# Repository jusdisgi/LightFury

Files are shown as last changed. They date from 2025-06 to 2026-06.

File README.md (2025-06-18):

# Light Fury

This is a 54-key, ergonomic split keyboard with a few tricks. Some of the features include:
- 1.69in color [LCD screen](https://www.waveshare.com/product/displays/lcd-oled/lcd-oled-3/1.69inch-lcd-module.htm)
- Per-key LEDs, using [WS2812B-2020](https://www.adafruit.com/product/4684)
- A roller encoder based on [CKW12](https://github.com/kumamuk-git/CKW12/tree/main) by Kumamuk, but integrated into the main PCB
- Kailh [PG1316S](https://holykeebs.com/products/kailh-pg1316s-butterfly-switch-10-pack) ultra-low profile switches
- A totally absurd [battery](https://www.digikey.com/en/products/detail/maker-emporium-ltd/PIS-1131/13283430) to run all of this stuff...5Ahr!!

## Schematics and Ergogen, just like PB and Chocolate!
If that seems absurd to you, you need to read [my new doc](https://github.com/jusdisgi/LightFury/blob/main/Schematics_and_Ergogen.md)

## Work in Progress

I think it might be done? Could it be?
Please take a look and let me know if you see anything wrong!

## Where is everything?
[Left Half PCB](https://github.com/jusdisgi/LightFury/blob/main/lightfury_left.kicad_pcb)
[Right Half PCB](https://github.com/jusdisgi/LightFury/blob/main/lightfury_right.kicad_pcb)

[Left Half Schematic](https://github.com/jusdisgi/LightFury/blob/main/lightfury_left.kicad_sch)
[Right Half Schematic](https://github.com/jusdisgi/LightFury/blob/main/lightfury_right.kicad_sch)

[Ergogen Config](https://github.com/jusdisgi/LightFury/blob/main/config.yaml)

## Some pics of the design



*the name has been chosen by the intended end-user, but will not be applied to the board until it actually exists in the real world.

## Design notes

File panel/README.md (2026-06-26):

# LightFury panelization (KiKit)

Run on **your machine** (KiKit drives KiCad's `pcbnew` — it won't run in the sandbox). The
per-half boards (`lightfury_left/right.kicad_pcb`) are the source of truth; everything below
rebuilds the combined board and panel from them, so re-run it any time a half changes.

**Environment:** use the **KiCad Command Prompt** (so `python` = KiCad's Python with `pcbnew`).
KiKit's `kikit.exe` installs to `...KiCad\9.0\3rdparty\Python311\Scripts`, which isn't on PATH by
default — add it for the session before the `kikit` commands:

```bat
set PATH=%PATH%;C:\Users\hunte\Documents\KiCad\9.0\3rdparty\Python311\Scripts
```

## Full workflow (in order)

```bash
cd LightFury

# 1. Merge the two halves -> lightfury_both.kicad_pcb (right-half refs get a _2 suffix,
#    nets get L_/R_ prefixes so the halves stay electrically distinct). Replaces the old
#    by-hand merge.
python panel/merge_both.py

# 2. Frame it into a panel.
kikit panelize -p panel/lightfury.kikit.json lightfury_both.kicad_pcb panel/lightfury_panel.kicad_pcb

# 3. GERBERS ONLY from the panel: open it in pcbnew and run the **Fabrication Toolkit** plugin
#    (NOT `kikit fab jlcpcb` — needs a schematic the _2 refs can't match). It writes to the
#    transient panel/production/ ; copy the gerber zip up to the canonical order folder:
copy panel\production\lightfury_panel.zip production-panel\

# 4. BOM + CPL straight from the panel (origin datum, integer rotations, RESW1 injected,
#    per-part offsets) -> the canonical production-panel/ . Then render to verify locally.
python panel/gen_cpl.py panel/lightfury_panel.kicad_pcb production-panel
python panel/render_cpl.py panel/lightfury_panel.kicad_pcb production-panel/positions.csv panel/verify
```

The three files you upload to JLC live in **production-panel/**. Full detail + the one-time JLC
rotation-confirmation step: **CPL_WORKFLOW.md**.

## Notes / gotchas

- **`post.millradius` eats the RE1 foot cutouts.** The CKW12 encoder has two ~2 mm diamond
  (45°-square) Edge.Cuts cutouts per half for RE1's feet. `millradius` simulates a 1 mm-radius
  (2 mm Ø) router bit across the *whole* substrate — including internal holes — so a sub-bit-size
  cutout gets erased. Result: the diamonds are in `lightfury_both` but vanish from the panel.
  Fix is in the preset: use **`millradiusouter`** (mills only the outer ring, leaves internal
  cutouts intact) instead of `millradius`. If your KiKit predates `millradiusouter`, set
  `millradius` to `0mm` and re-inject the 4 diamonds afterward (translate the both-board loops by
  the panel placement offset — footprint-only, so BOM/CPL are untouched). **Always eyeball the
  encoder cutouts in the panel before ordering.**
- **`merge_both.py`** is the script that replaces your old hand-merge. Right-half refs become
  `*_2` (uniform — simpler than the old mixed RS/RLED/_2 scheme; JLC only cares that refs are
  unique and that BOM ↔ CPL agree, which they will since both come from this pipeline).
  `appendBoard`'s signature is the line most likely to need a tweak for your KiKit version.
- **Prereq:** the per-half schematics need their `LCSC` fields filled and pushed to the PCBs
  (Update PCB from Schematic / F8) *before* step 1, or the BOM comes out without part numbers.
- **`gen_cpl.py`** (pure Python, no pcbnew) builds the BOM + CPL directly from the panel: position
  = footprint origin, per-LCSC `ROT_CORR`/`POS_OVERRIDE` tables, and RESW1 (C262417) injected from
  the encoder's S1/S2 pads. It supersedes the old `inject_resw1.py` (now in `old_cruft/`).
  `render_cpl.py` overlays the result on the real pads for local verification before uploading.
- The preset's 1×1 grid frames the merged pair (two outlines) as one unit, bridging each half
  to the rails with mouse-bite tabs. If KiKit complains about the two outlines, the fallback is
  to move framing into `merge_both.py` (KiKit Python API) — ping me and I'll extend it.

## Preset details (lightfury.kikit.json)

- **Rails** top & bottom, 5 mm, 3 mm gap (`railstb`).
- **Tabs** every 25 mm, 3 mm wide, **mouse-bites** (0.5 mm drills @ 0.8 mm) — better than V-cuts
  for the filleted/curved outlines.
- **Tooling holes** (1.5 mm) and **fiducials** (1 mm copper / 2 mm mask) in the rail corners.
- `JLCJLCJLCJLC` order token in the rail, `millradius 1 mm` for the router.

## Tune after first run

- Tighten `GAP_MM` in `merge_both.py` if the halves sit too far apart (tighter = cheaper panel).
- Check the panel against JLC's rules (min rail width, mouse-bite spacing); bump tab count if any
  edge feels under-supported for the 5 Ah / LCD weight during assembly.
- Verify RESW1 (and any consigned/extended parts) in JLC's BOM/assembly preview before ordering.

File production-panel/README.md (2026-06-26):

# LightFury — JLCPCB order set

**These three files are what you upload to JLCPCB. Nothing else.**

| file | what it is | upload as |
|---|---|---|
| `lightfury_panel.zip` | Gerbers + drill for the full panel (both halves, frame, mouse-bites) | Gerber |
| `bom.csv` | Bill of materials (one line per LCSC part, RESW1 included) | BOM |
| `positions.csv` | Pick-and-place / CPL (origin datum, integer rotations, per-part offsets applied) | CPL |

The gerber is uploaded once at the **start** of the JLC order (before PCBA). The BOM/CPL are
uploaded in the PCBA step and can be re-uploaded freely. **You only need a fresh gerber when the
copper changes** (re-panelize or a half edit) — pure rotation/position tweaks ride on the CPL alone.

## Regenerating these

Full procedure and the hard rules live in [`../panel/CPL_WORKFLOW.md`](../panel/CPL_WORKFLOW.md).
Short version, run from the repo root, all from the **same** panel generation:

```bat
:: gerbers: open panel\lightfury_panel.kicad_pcb in KiCad, run the Fabrication Toolkit,
:: then copy its output zip up here:
copy panel\production\lightfury_panel.zip production-panel\

:: BOM + CPL straight from the same panel file:
python panel\gen_cpl.py panel\lightfury_panel.kicad_pcb production-panel

:: optional local sanity render (writes PNGs to panel\verify\):
python panel\render_cpl.py panel\lightfury_panel.kicad_pcb production-panel\positions.csv panel\verify
```

Gerbers and CPL **must** come from the same panel generation or parts land on stale copper — that
was the multi-hour failure of 18 Jun (a frozen gerber under a changing CPL).

## Part-specific notes baked into `gen_cpl.py`

- Rotations and position offsets for the oddball parts (PWR1, CONN1, RE1, RESW1, the SOT-23s,
  LEDs, diodes, switches) are in the `ROT_CORR` / `POS_OVERRIDE` tables at the top of `gen_cpl.py`.
- **PG1316S** switches are consigned (`C9900170245`); the **nice!nano**, **Waveshare LCD**, JST
  battery connector and M2 mounting holes are hand-assembled — none appear in this BOM/CPL by design.

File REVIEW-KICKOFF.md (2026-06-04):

# LightFury — review & optimize: session kickoff

Goal: review the **already-routed** LightFury board (its README literally asks "let me know if you see
anything wrong"), fix only genuine functional problems, and panel it for JLCPCB. **Preserve the
routing** — regenerate from ergogen only if a real defect forces it (it wipes routing).

## Context
- 54-key ergo split — the "Swiss Army chainsaw" to xiphos's scalpel. Features: 1.69" Waveshare color
  **LCD**, **per-key WS2812B-2020 RGB** (~54/half — heat-sensitive, fine-pitch → this is exactly why
  it must be JLC PCBA, not hot-plate), **CKW12 roller encoder** integrated into the PCB, PG1316S
  switches, an absurd **5Ah battery**, nice!nano.
- Has schematics (`lightfury_left.kicad_sch` / `_right`) built via the `Schematics_and_Ergogen.md`
  workflow (the guide is present in this repo), routed `lightfury_left/right/both.kicad_pcb`, and a
  `Production_JLCPCBA/` folder.
- The workspace `../CLAUDE.md` "Schematics, combined boards & production" section applies.
- **No `CLAUDE.md` yet** — create one (model on `../zmk-config-totem/CLAUDE.md`).

## First steps
1. Read `config.yaml`, the routed PCBs, schematics, and `Production_JLCPCBA/` BOM/CPL. Write
   `LightFury/CLAUDE.md`.
2. **Design review** (what the README invites): verify the **WS2812 data chain** (DIN→DOUT order
   continuous and sane), LED/LCD/encoder power + signal nets, decoupling, and schematic ↔ PCB parity.
   Flag issues — but remember fixes needing a config regen cost the routing.
3. **BOM completeness:** every part needs an LCSC number (LCD module, WS2812B-2020, CKW12 encoder,
   EZmate, power/reset switches, PG1316S consigned `C9900170245`); nano DNP / hand-soldered. Sort out
   what's JLC-stockable vs consigned vs hand-placed.
4. **Panelize with KiKit** (multiboard — this board is large, so nesting matters more for cost): rails,
   mouse-bites, fiducials, tooling. Claude writes the config; Hunter runs it.

git: hands-off — write the commands, don't run them.

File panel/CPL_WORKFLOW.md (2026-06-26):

# LightFury CPL / BOM workflow

How to produce a **correct** JLCPCB pick-and-place (CPL) + BOM for the panel — and why the
old way kept failing. Read this before touching the production files.

## What went wrong last time (so we never repeat it)

The boards, schematics, and gerbers were always fine. Every failure was in the CPL, and the
causes were:

1. **Debugging by eyeballing JLC's web preview.** You can't read an offset vector off a rotated
   2 mm part in a browser, so every "fix" was a guess tested through a slow round-trip.
2. **Four bugs tangled together:** the fractional `TILT=10.9` (→ every part on a `.9°` angle that
   JLC rounds, read as "1° off"); per-part pin-1 rotation corrections; an *origin-vs-centroid*
   position question; and **stale-generation drift** — the CPL being regenerated against a
   different panel than the gerbers that got uploaded.
3. **The pad-centroid "correction" was itself the position bug.** Verified against the board's
   F.Fab body outlines: the footprint **origin already sits at each part's body center**, which is
   exactly JLC's placement datum. The pad centroid is *skewed* on any asymmetric part
   (Molex −1.8 mm, encoder +2.4 mm, all 54 PG1316S +0.9 mm, BAV70 +0.4 mm). The old inject
   script shifted everything to the centroid and dragged good parts off their pads.
4. **Post-hoc deltas on a moving baseline.** Corrections were layered on top of toolkit output
   that itself changed between runs (auto-translate on/off, re-export), and weren't idempotent.

## The rule set we proved correct

- **Position = footprint origin**, nothing else. (Origin = body center = JLC datum for every part
  on this board. Confirmed against F.Fab outlines + the gerber Edge.Cuts bbox.)
- **CPL origin = panel Edge.Cuts top-left**, Y flipped. This is *exactly* the origin KiCad/the
  Fabrication Toolkit uses when it plots the gerbers (gerber bbox `X[0,184.313] Y[-234.012,0]`
  matches the panel bbox `X[56.343,240.657] Y[20,254.012]` — same W/H, tl origin). So CPL and
  gerbers share one frame **by construction** → no global offset.
- **Rotation = footprint orientation + a per-LCSC correction.** Keep `TILT` an **integer** so every
  part lands on a whole degree. Only oriented parts whose pin-1 differs from JLC's library need a
  nonzero correction.
- **Single source of truth.** The CPL is generated directly from `lightfury_panel.kicad_pcb` — the
  same file the gerbers come from. Never hand-patch positions again.

## The tools (pure Python, no pcbnew — run anywhere)

- `kicad_panel.py` — parses the `.kicad_pcb` (footprints, pads, F.Fab outlines, Edge.Cuts bbox).
- `gen_cpl.py` — writes `positions.csv` + `bom.csv` from the panel. Idempotent.
- `render_cpl.py` — draws the placement points over the real copper pads as PNGs for **local**
  verification, so we confirm correctness *before* uploading anything.

## Procedure

Run these on the **same** panel file, in lockstep, every time the board changes:

```bat
cd C:\Users\hunte\Documents\gittyup\LightFury

:: 1. (if layout changed) re-merge + re-panelize so panel matches the halves
python panel\merge_both.py
kikit panelize -p panel\lightfury.kikit.json lightfury_both.kicad_pcb panel\lightfury_panel.kicad_pcb

:: 2. export GERBERS from panel\lightfury_panel.kicad_pcb (Fabrication Toolkit -> panel\production\),
::    then copy the zip up into the canonical order folder:
copy panel\production\lightfury_panel.zip production-panel\

:: 3. generate the CPL + BOM from the SAME panel file, straight into production-panel\
python panel\gen_cpl.py panel\lightfury_panel.kicad_pcb production-panel

:: 4. LOCAL verification — render onto the real pads and eyeball before uploading
python panel\render_cpl.py panel\lightfury_panel.kicad_pcb production-panel\positions.csv panel\verify
start panel\verify\verify_overview.png
start panel\verify\verify_parts.png
```

Upload to JLC: the three files in **`production-panel\`** — `lightfury_panel.zip` + `positions.csv` + `bom.csv`.

## The one remaining manual step: confirm rotations (do this ONCE)

Positions are now exact. The only thing the board geometry can't tell us is how JLC's library part
is oriented on its reel vs our footprint. Resolve it in a **single clean pass** — don't nudge
iteratively:

1. Upload and open JLC's assembly preview.
2. For each **oriented** part type (LED, BAV70 diode, the two SOT-23 ICs, power/reset switches,
   Molex connector, encoder, RESW), read whether it needs 0/90/180/270°. JLC's editor gives exact
   values — read, don't guess.
3. Put each into `ROT_CORR` in `gen_cpl.py`, keyed by LCSC. `C965555` (LED) = 180 is already
   confirmed. Re-run step 3 above (positions are unaffected) and re-upload.

If a part's *body* ever looks off its pads in JLC (not just rotated), that's a datum exception —
add a `POS_OVERRIDE[lcsc] = (dx, dy)` in part-local mm. None are expected on this board.

## Hard rules

- `TILT` in `merge_both.py` stays an **integer**.
- Gerbers and CPL always come from the **same** `lightfury_panel.kicad_pcb` generation. If you
  re-panelize, you re-export both. No mixing generations.
- `inject_resw1.py` is **superseded** by `gen_cpl.py` and kept only for reference. Don't run it.

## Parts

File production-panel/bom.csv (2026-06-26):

Designator | Footprint | Quantity | Value | LCSC Part #
D1, D10, D10_2, D11, D11_2, D12, D12_2, D13, D13_2, D14, D14_2, D1_2, D2, D2_2, D3, D3_2, D4, D4_2, D5, D5_2, D6, D6_2, D7, D7_2, D8, D8_2, D9, D9_2 | BAV70 SOT23 | 28 | BAV70 | C68978
S1, S10, S10_2, S11, S11_2, S12, S12_2, S13, S13_2, S14, S14_2, S15, S15_2, S16, S16_2, S17, S17_2, S18, S18_2, S19, S19_2, S1_2, S2, S20, S20_2, S21, S21_2, S22, S22_2, S23, S23_2, S24, S24_2, S25, S25_2, S26, S26_2, S27, S27_2, S2_2, S3, S3_2, S4, S4_2, S5, S5_2, S6, S6_2, S7, S7_2, S8, S8_2, S9, S9_2 | PG1316S | 54 | PG1316S | C9900170245
R2, R2_2 | Resistor_SMD:R_0603_1608Metric | 2 | 51kΩ | C23196
RE1, RE1_2 | CKW12 | 2 | CKW12 | C202421
LED1, LED10, LED10_2, LED11, LED11_2, LED12, LED12_2, LED13, LED13_2, LED14, LED14_2, LED15, LED15_2, LED16, LED16_2, LED17, LED17_2, LED18, LED18_2, LED19, LED19_2, LED1_2, LED2, LED20, LED20_2, LED21, LED21_2, LED22, LED22_2, LED23, LED23_2, LED24, LED24_2, LED25, LED25_2, LED26, LED26_2, LED27, LED27_2, LED2_2, LED3, LED3_2, LED4, LED4_2, LED5, LED5_2, LED6, LED6_2, LED7, LED7_2, LED8, LED8_2, LED9, LED9_2 | LED_WS2812B-2020_PLCC4_2.0x2.0mm | 54 | WS2812B-2020 | C965555
R1, R1_2 | Resistor_SMD:R_0603_1608Metric | 2 | 470kΩ | C23178
RST1, RST1_2 | ceoloide:reset_switch_smd_side | 2 | Reset SW | C79174
CONN1, CONN1_2 | Molex_PicoBlade_53261-0871_1x08-1MP_P1.25mm_Horizontal | 2 | LCD HEADER | C293349
C2, C2_2, C4, C4_2, C5, C5_2 | Capacitor_SMD:C_0603_1608Metric | 6 | 10μF 25V | C91606
C3, C3_2 | Capacitor_SMD:C_0603_1608Metric | 2 | 100nF | C14663
U2, U2_2 | Package_TO_SOT_SMD:SOT-23-5 | 2 | SN74LV1T126DBVR | C2440228
PWR1, PWR1_2 | ceoloide:power_switch_smd_side | 2 | Power SW | C2911519
L1, L1_2 | huntercook:L_CJIANG_FTC404030S_4.1x4.1x3.0_SMD | 2 | 2.2μH | C39676081
U1, U1_2 | Package_TO_SOT_SMD:SOT-23-6 | 2 | TLV61070ADBV | C6881375
C1, C1_2 | Capacitor_SMD:C_0603_1608Metric | 2 | 10μF | C1691
RESW1, RESW1_2 | CKW12 | 2 | CKW12 Switch | C262417

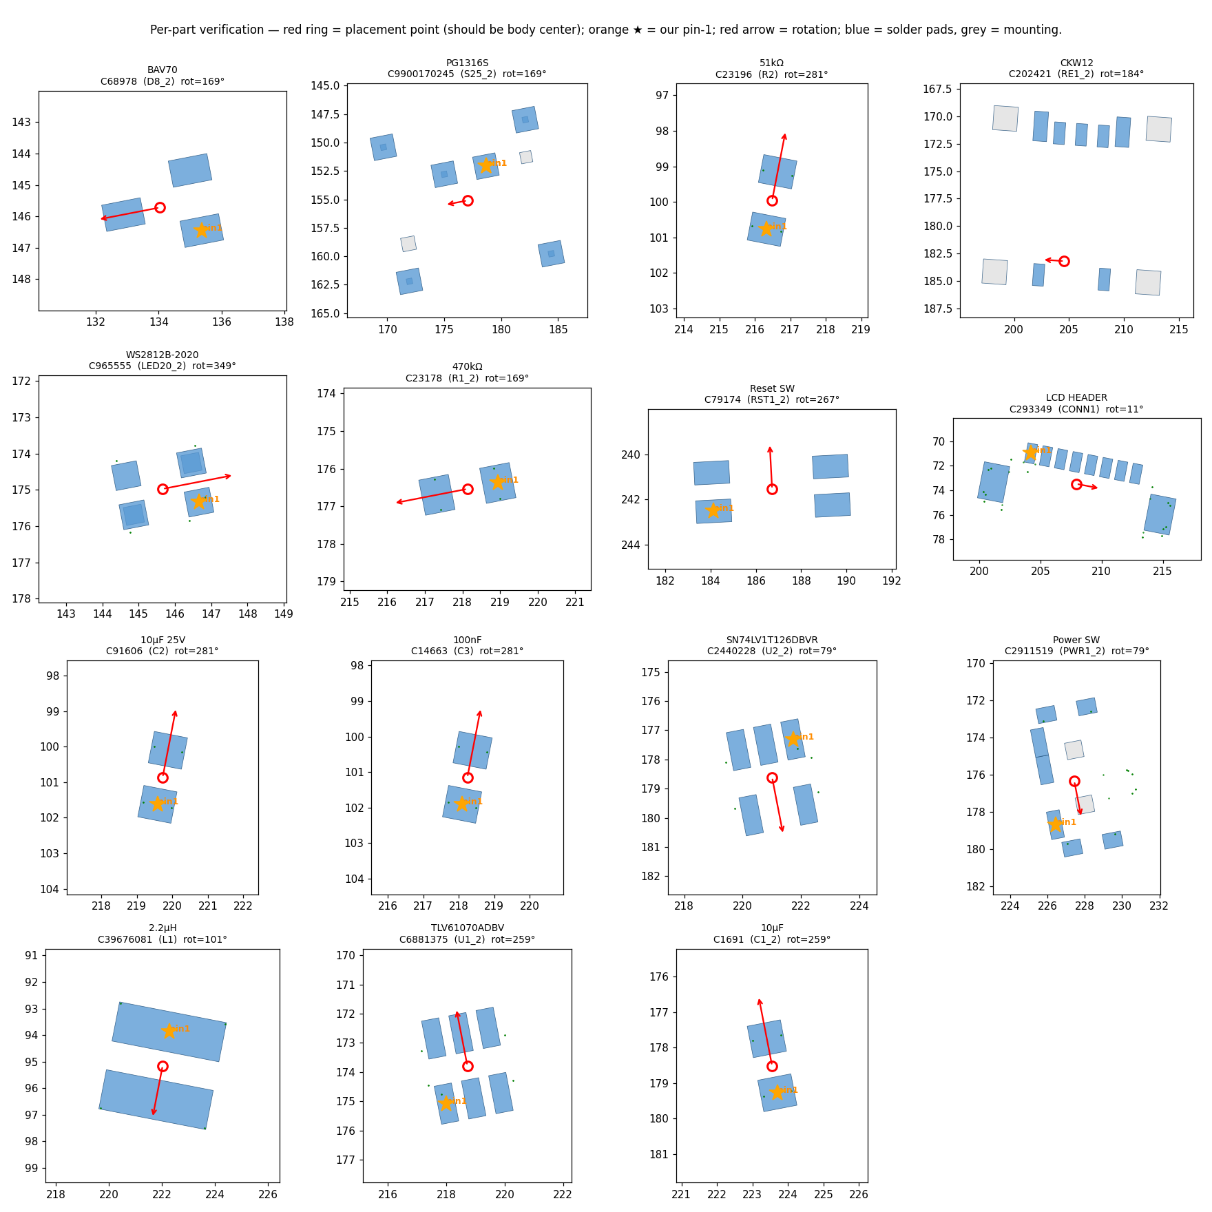
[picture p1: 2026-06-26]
panel/verify/verify_parts.png

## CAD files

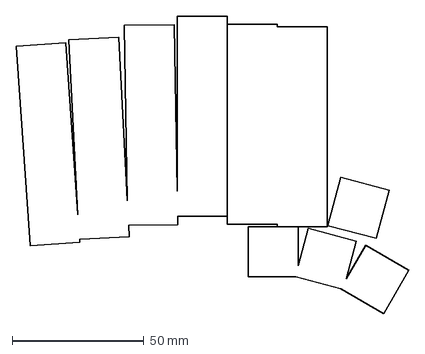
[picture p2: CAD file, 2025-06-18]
output/outlines/case_keycuts_left.dxf
149.3 x 113.1 mm

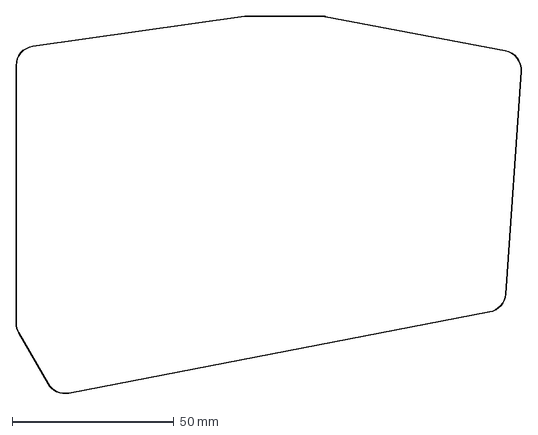
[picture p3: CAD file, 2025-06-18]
output/outlines/board_right.dxf
156.2 x 116.9 mm

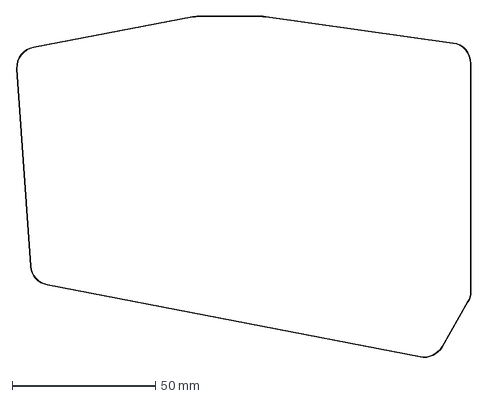
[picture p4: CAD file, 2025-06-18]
output/outlines/case_outer_wall_left.dxf
158.7 x 119.4 mm

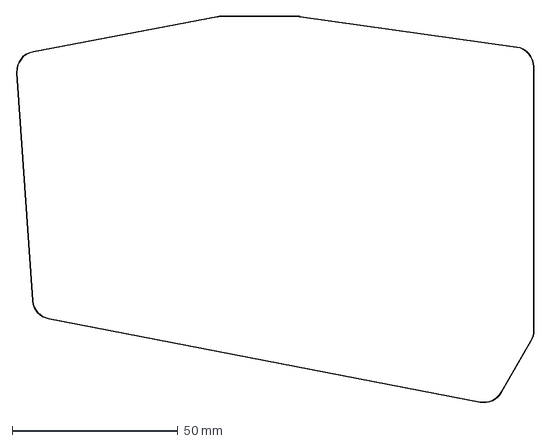
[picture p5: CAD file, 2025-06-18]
output/outlines/board_left.dxf
156.2 x 116.9 mm

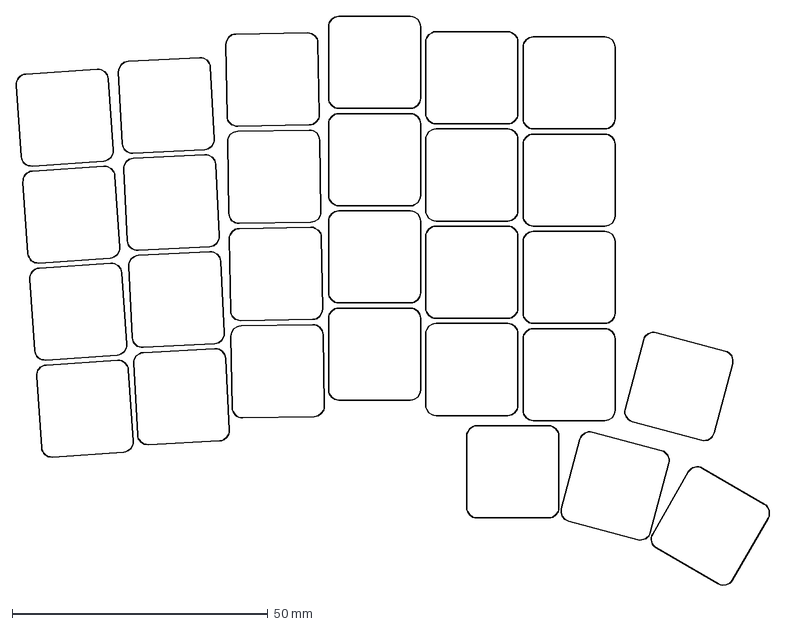
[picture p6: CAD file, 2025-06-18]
output/outlines/keycap_outlines_left.dxf
147.5 x 111.4 mm

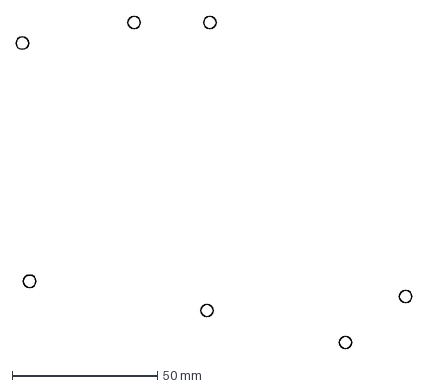
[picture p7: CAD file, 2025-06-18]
output/outlines/spacers_left.dxf
136.0 x 114.3 mm

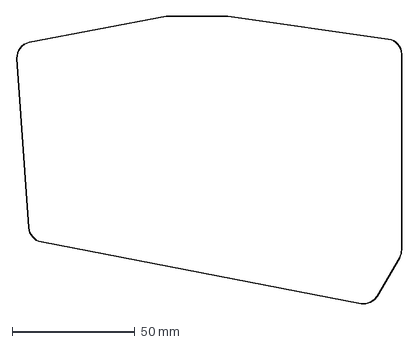
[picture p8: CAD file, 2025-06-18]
output/outlines/case_inner_wall_left.dxf
156.6 x 117.3 mm

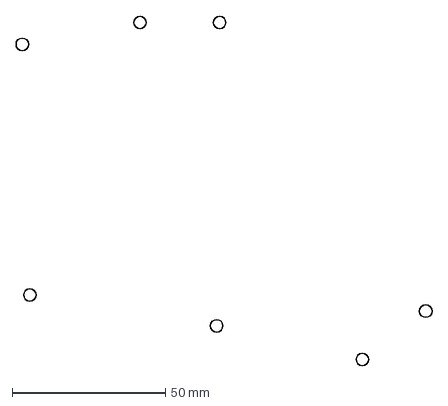
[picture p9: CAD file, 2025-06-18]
output/outlines/screw_heads_left.dxf
135.8 x 114.1 mm

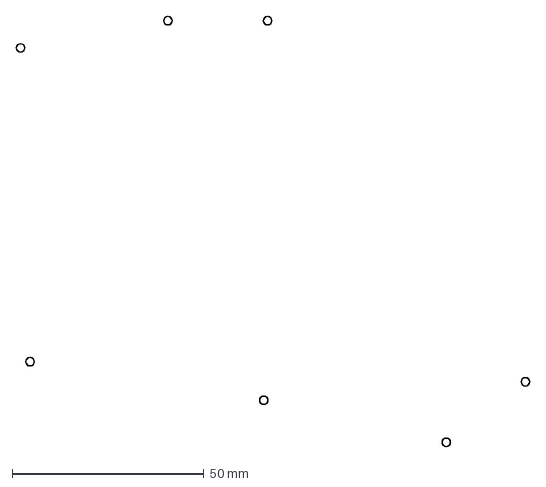
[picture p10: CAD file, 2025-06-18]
output/outlines/screws_left.dxf
133.9 x 112.2 mm

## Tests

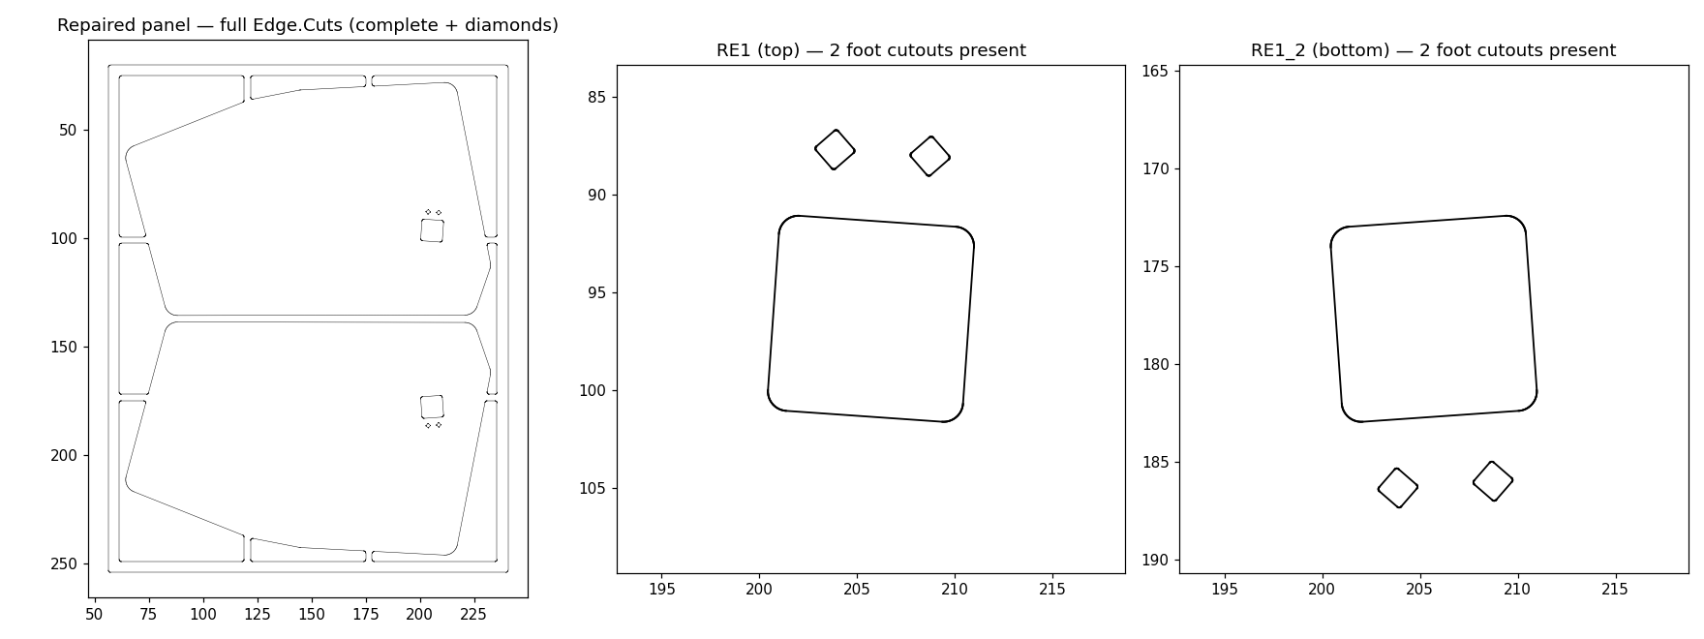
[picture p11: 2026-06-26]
panel/verify/panel_edgecuts_verify.png

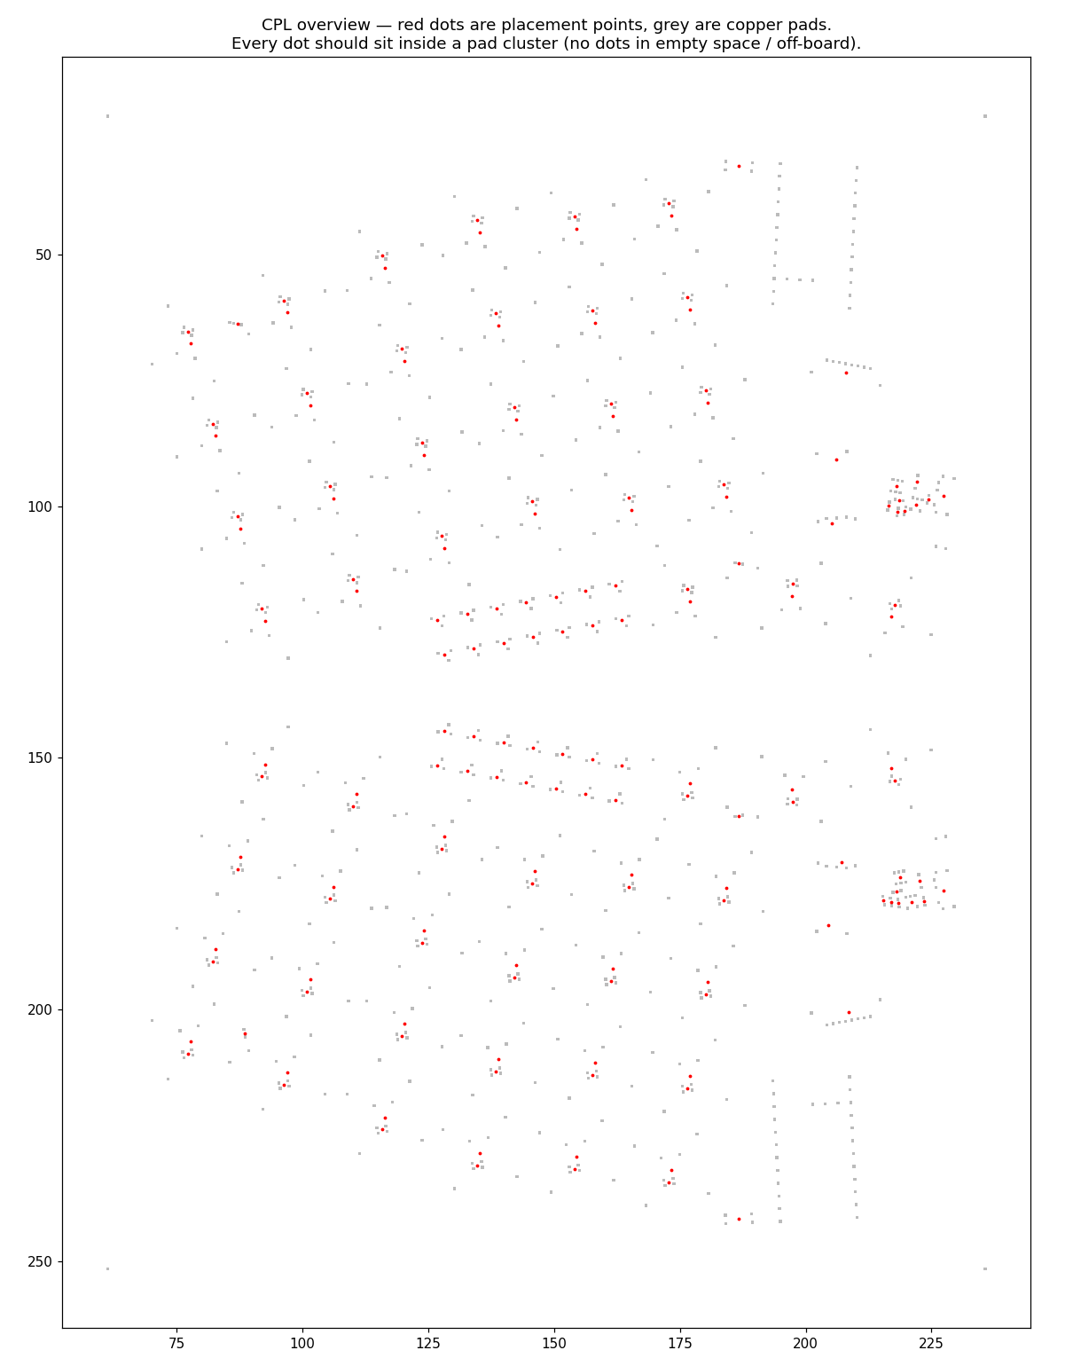
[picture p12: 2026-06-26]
panel/verify/verify_overview.png

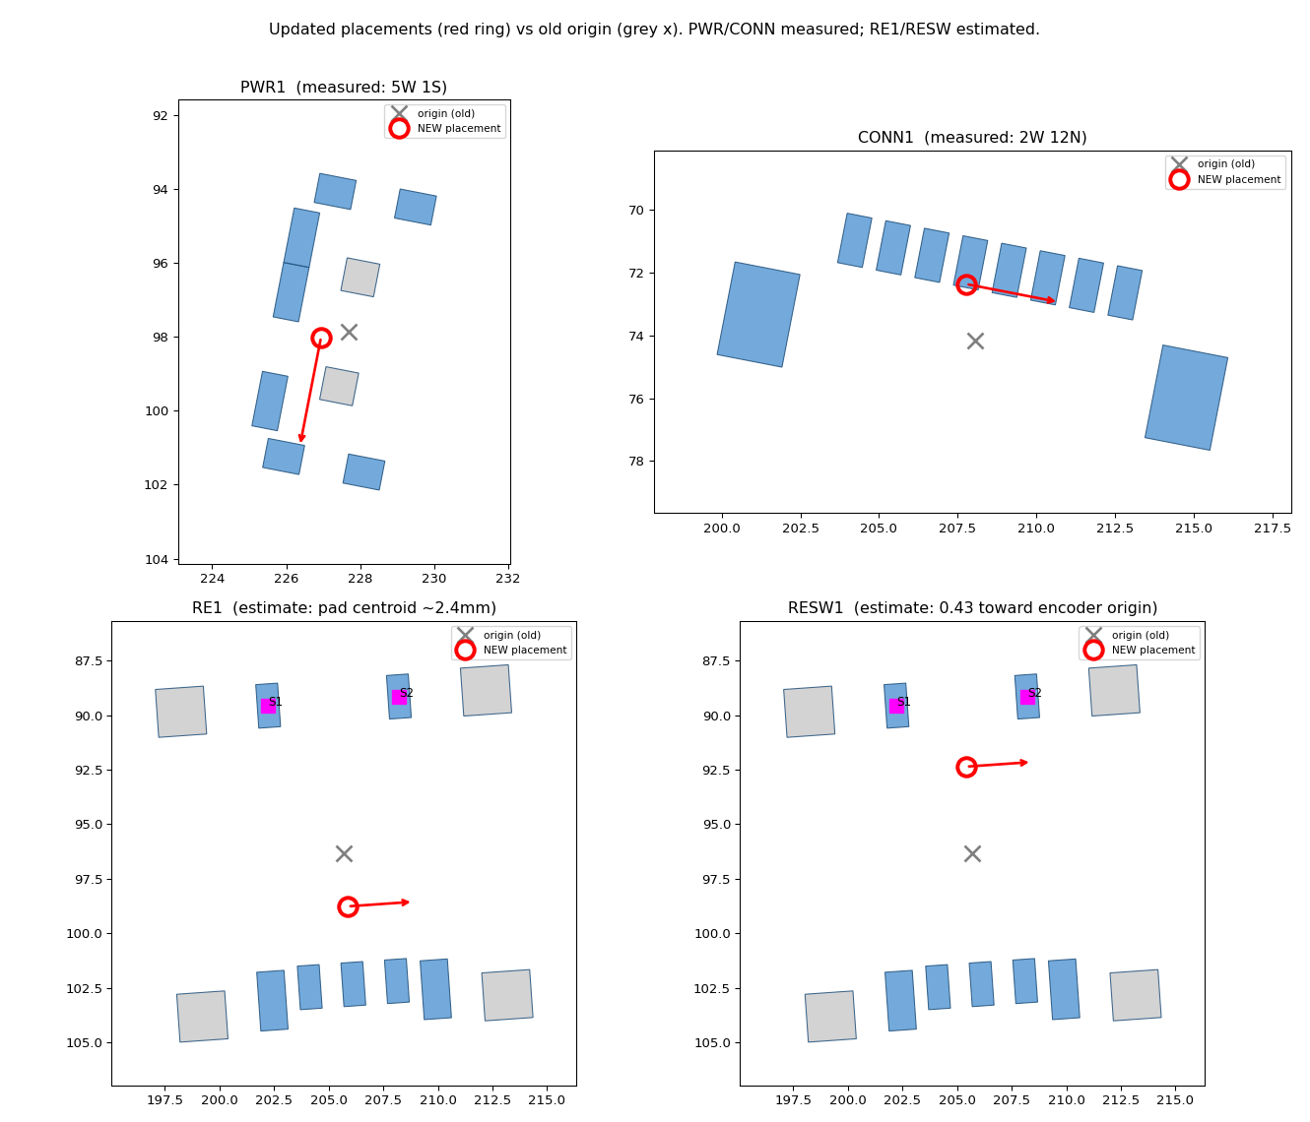
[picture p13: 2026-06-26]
panel/verify/verify_fixed4.png

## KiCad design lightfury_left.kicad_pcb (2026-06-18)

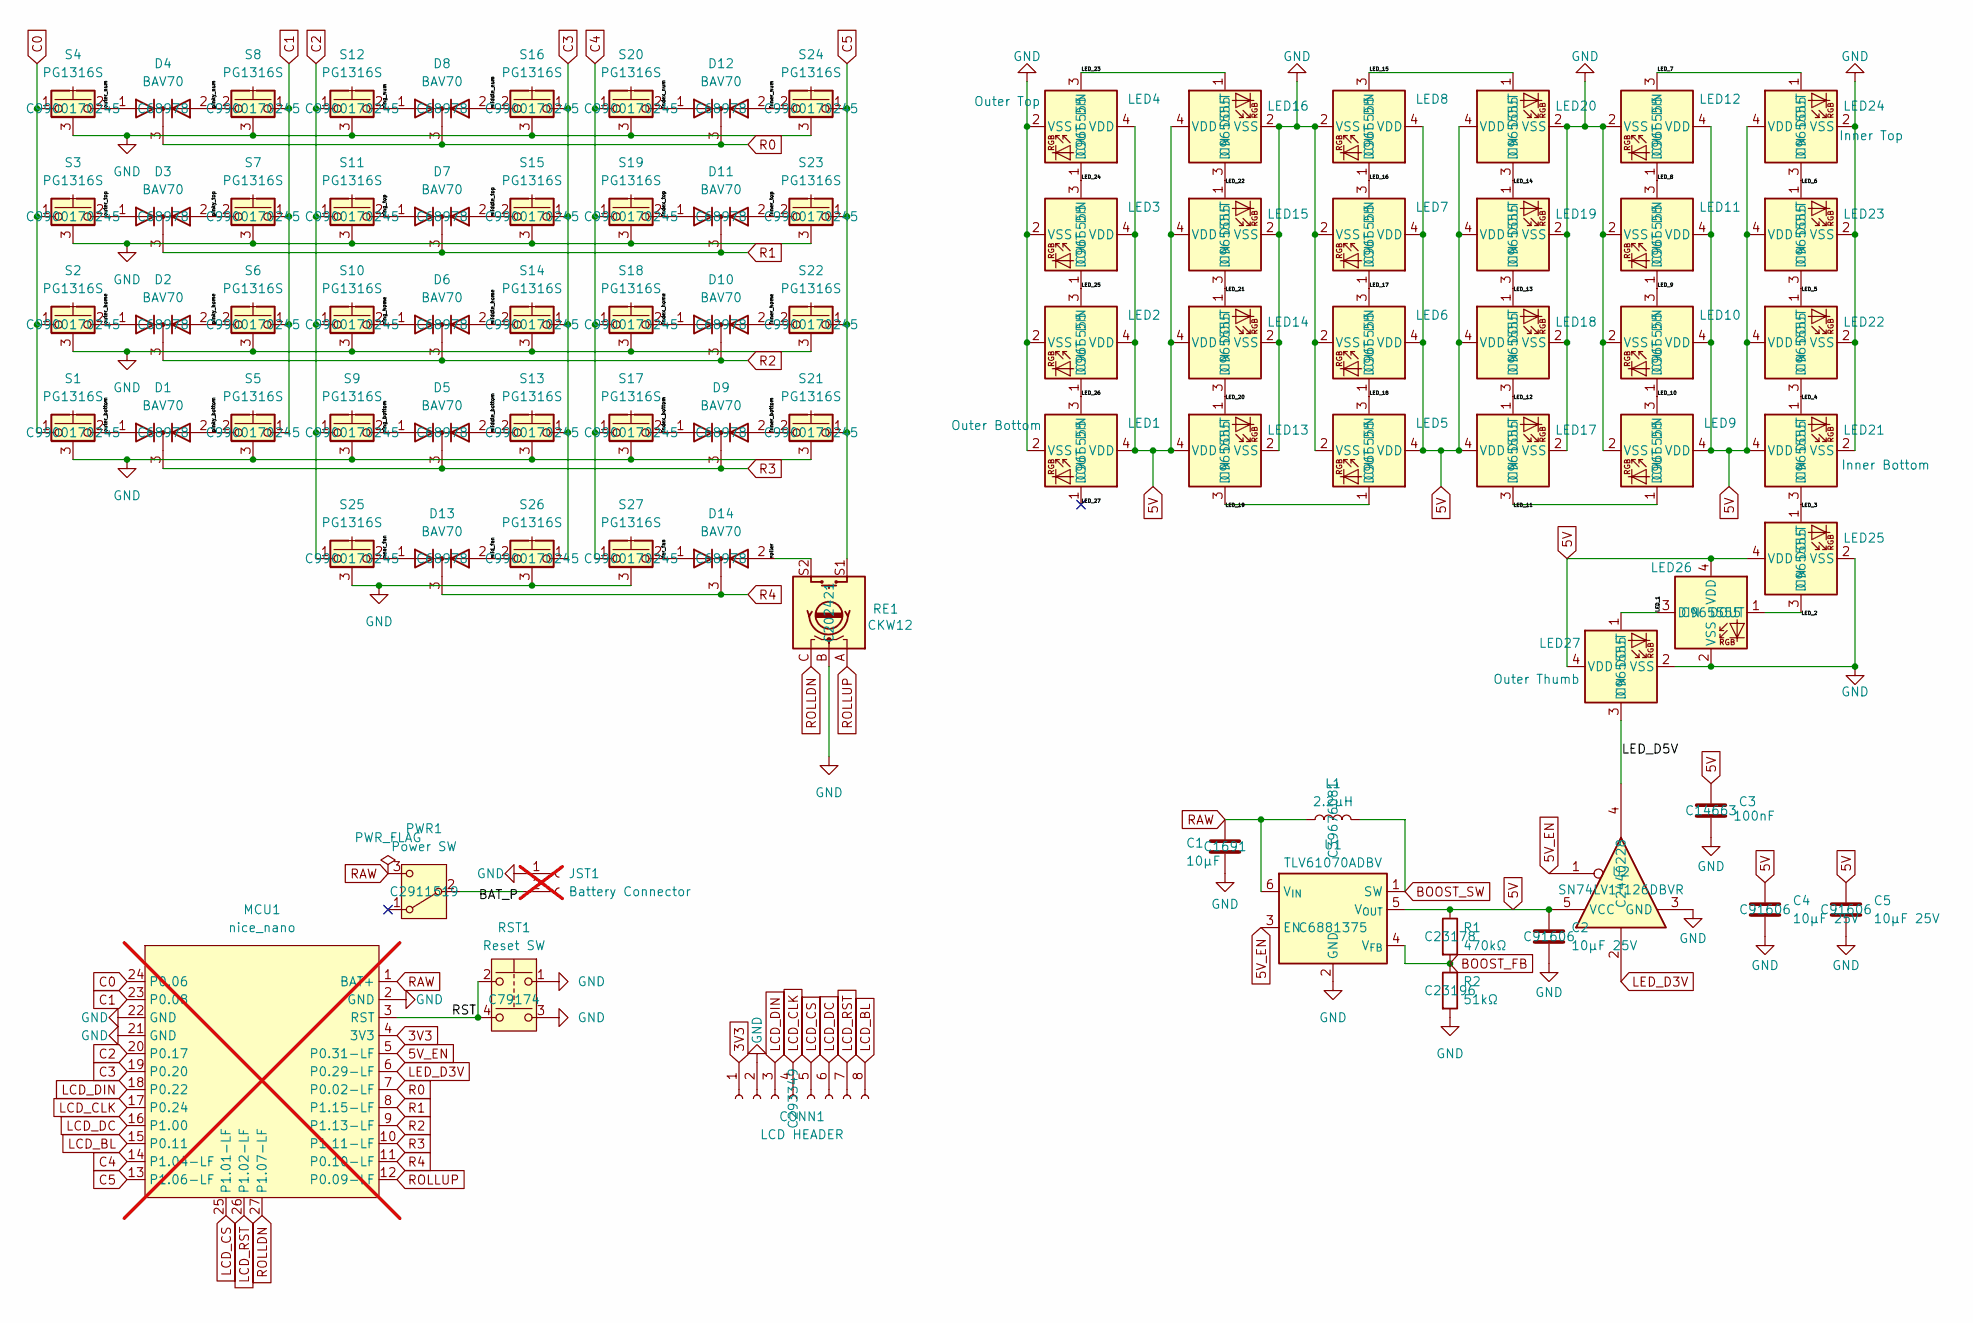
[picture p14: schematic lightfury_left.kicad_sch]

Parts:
C1: 10μF; C_0603_1608Metric; LCSC C1691
C2: 10μF 25V; C_0603_1608Metric; LCSC C91606
C3: 100nF; C_0603_1608Metric; LCSC C14663
C4, C5: 10µF 25V; C_0603_1608Metric; LCSC C91606
CONN1: LCD HEADER; Molex_PicoBlade_53261-0871_1x08-1MP_P1.25mm_Horizontal; LCSC C293349
D1, D2, D3, D4, D5, D6, D7, D8, D9, D10, D11, D12, D13, D14: BAV70; BAV70 SOT23; LCSC C68978
JST1: Battery Connector; battery_connector_jst_ph_2; not fitted
L1: 2.2μH; L_CJIANG_FTC404030S_4.1x4.1x3.0_SMD; LCSC C39676081
LED1: Outer Bottom; LED_WS2812B-2020_PLCC4_2.0x2.0mm; LCSC C965555
LED2, LED3, LED5, LED6, LED7, LED8, LED9, LED10, LED11, LED12, LED13, LED14, LED15, LED16, LED17, LED18, LED19, LED20, LED22, LED23, LED25, LED26: WS2812B-2020; LED_WS2812B-2020_PLCC4_2.0x2.0mm; LCSC C965555
LED4: Outer Top; LED_WS2812B-2020_PLCC4_2.0x2.0mm; LCSC C965555
LED21: Inner Bottom; LED_WS2812B-2020_PLCC4_2.0x2.0mm; LCSC C965555
LED24: Inner Top; LED_WS2812B-2020_PLCC4_2.0x2.0mm; LCSC C965555
LED27: Outer Thumb; LED_WS2812B-2020_PLCC4_2.0x2.0mm; LCSC C965555
MCU1: nice_nano; mcu_nice_nano; not fitted
PWR1: Power SW; power_switch_smd_side; LCSC C2911519
R1: 470kΩ; R_0603_1608Metric; LCSC C23178
R2: 51kΩ; R_0603_1608Metric; LCSC C23196
RE1: CKW12; LCSC C202421
RST1: Reset SW; reset_switch_smd_side; LCSC C79174
S1, S2, S3, S4, S5, S6, S7, S8, S9, S10, S11, S12, S13, S14, S15, S16, S17, S18, S19, S20, S21, S22, S23, S24, S25, S26, S27: PG1316S; LCSC C9900170245
U1: TLV61070ADBV; SOT-23-6; LCSC C6881375
U2: SN74LV1T126DBVR; SOT-23-5; LCSC C2440228

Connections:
3V3: CONN1.1, MCU1.4 (3V3)
5V: C2.1, C3.1, C4.1, C5.1, LED1.4 (VDD), LED2.4 (VDD), LED3.4 (VDD), LED4.4 (VDD), LED5.4 (VDD), LED6.4 (VDD), LED7.4 (VDD), LED8.4 (VDD), LED9.4 (VDD), LED10.4 (VDD), LED11.4 (VDD), LED12.4 (VDD), LED13.4 (VDD), LED14.4 (VDD), LED15.4 (VDD), LED16.4 (VDD), LED17.4 (VDD), LED18.4 (VDD), LED19.4 (VDD), LED20.4 (VDD), LED21.4 (VDD), LED22.4 (VDD), LED23.4 (VDD), LED24.4 (VDD), LED25.4 (VDD), LED26.4 (VDD), LED27.4 (VDD), R1.1, U1.5 (V_{OUT}), U2.5 (VCC)
5V_EN: MCU1.5 (P0.31-LF), U1.3 (EN), U2.1
/BAT_P: JST1.2, PWR1.2 (B)
/LED_1: LED26.3 (DIN), LED27.1 (DOUT)
/LED_2: LED25.3 (DIN), LED26.1 (DOUT)
/LED_3: LED21.3 (DIN), LED25.1 (DOUT)
/LED_4: LED21.1 (DOUT), LED22.3 (DIN)
/LED_5: LED22.1 (DOUT), LED23.3 (DIN)
/LED_6: LED23.1 (DOUT), LED24.3 (DIN)
/LED_7: LED12.3 (DIN), LED24.1 (DOUT)
/LED_8: LED11.3 (DIN), LED12.1 (DOUT)
/LED_9: LED10.3 (DIN), LED11.1 (DOUT)
/LED_10: LED9.3 (DIN), LED10.1 (DOUT)
/LED_11: LED9.1 (DOUT), LED17.3 (DIN)
/LED_12: LED17.1 (DOUT), LED18.3 (DIN)
/LED_13: LED18.1 (DOUT), LED19.3 (DIN)
/LED_14: LED19.1 (DOUT), LED20.3 (DIN)
/LED_15: LED8.3 (DIN), LED20.1 (DOUT)
/LED_16: LED7.3 (DIN), LED8.1 (DOUT)
/LED_17: LED6.3 (DIN), LED7.1 (DOUT)
/LED_18: LED5.3 (DIN), LED6.1 (DOUT)
/LED_19: LED5.1 (DOUT), LED13.3 (DIN)
/LED_20: LED13.1 (DOUT), LED14.3 (DIN)
/LED_21: LED14.1 (DOUT), LED15.3 (DIN)
/LED_22: LED15.1 (DOUT), LED16.3 (DIN)
/LED_23: LED4.3 (DIN), LED16.1 (DOUT)
/LED_24: LED3.3 (DIN), LED4.1 (DOUT)
/LED_25: LED2.3 (DIN), LED3.1 (DOUT)
/LED_26: LED1.3 (DIN), LED2.1 (DOUT)
/LED_27: LED1.1 (DOUT)
/LED_D5V: LED27.3 (DIN), U2.4
/RST: MCU1.3 (RST), RST1.2, RST1.4
/far_fan: D14.1 (A), S27.2
/index_bottom: D9.1 (A), S17.2
/index_home: D10.1 (A), S18.2
/index_num: D12.1 (A), S20.2
/index_top: D11.1 (A), S19.2
/inner_bottom: D9.2 (A), S21.2
/inner_home: D10.2 (A), S22.2
/inner_num: D12.2 (A), S24.2
/inner_top: D11.2 (A), S23.2
/mid_fan: D13.2 (A), S26.2
/middle_bottom: D5.2 (A), S13.2
/middle_home: D6.2 (A), S14.2
/middle_num: D8.2 (A), S16.2
/middle_top: D7.2 (A), S15.2
/near_fan: D13.1 (A), S25.2
/outer_bottom: D1.1 (A), S1.2
/outer_home: D2.1 (A), S2.2
/outer_num: D4.1 (A), S4.2
/outer_top: D3.1 (A), S3.2
/pinky_bottom: D1.2 (A), S5.2
/pinky_home: D2.2 (A), S6.2
/pinky_num: D4.2 (A), S8.2
/pinky_top: D3.2 (A), S7.2
/ring_bottom: D5.1 (A), S9.2
/ring_home: D6.1 (A), S10.2
/ring_num: D8.1 (A), S12.2
/ring_top: D7.1 (A), S11.2
/roller: D14.2 (A), RE1.S2
BOOST_FB: R1.2, R2.1, U1.4 (V_{FB})
BOOST_SW: L1.2, U1.1 (SW)
C0: MCU1.24 (P0.06), S1.1, S2.1, S3.1, S4.1
C1: MCU1.23 (P0.08), S5.1, S6.1, S7.1, S8.1
C2: MCU1.20 (P0.17), S9.1, S10.1, S11.1, S12.1, S25.1
C3: MCU1.19 (P0.20), S13.1, S14.1, S15.1, S16.1, S26.1
C4: MCU1.14 (P1.04-LF), S17.1, S18.1, S19.1, S20.1, S27.1
C5: MCU1.13 (P1.06-LF), RE1.S1, S21.1, S22.1, S23.1, S24.1
GND: C1.2, C2.2, C3.2, C4.2, C5.2, CONN1.2, JST1.1, LED1.2 (VSS), LED2.2 (VSS), LED3.2 (VSS), LED4.2 (VSS), LED5.2 (VSS), LED6.2 (VSS), LED7.2 (VSS), LED8.2 (VSS), LED9.2 (VSS), LED10.2 (VSS), LED11.2 (VSS), LED12.2 (VSS), LED13.2 (VSS), LED14.2 (VSS), LED15.2 (VSS), LED16.2 (VSS), LED17.2 (VSS), LED18.2 (VSS), LED19.2 (VSS), LED20.2 (VSS), LED21.2 (VSS), LED22.2 (VSS), LED23.2 (VSS), LED24.2 (VSS), LED25.2 (VSS), LED26.2 (VSS), LED27.2 (VSS), MCU1.2 (GND), MCU1.21 (GND), MCU1.22 (GND), R2.2, RE1.B, RST1.1, RST1.3, S1.3 (B), S2.3 (B), S3.3 (B), S4.3 (B), S5.3 (B), S6.3 (B), S7.3 (B), S8.3 (B), S9.3 (B), S10.3 (B), S11.3 (B), S12.3 (B), S13.3 (B), S14.3 (B), S15.3 (B), S16.3 (B), S17.3 (B), S18.3 (B), S19.3 (B), S20.3 (B), S21.3 (B), S22.3 (B), S23.3 (B), S24.3 (B), S25.3 (B), S26.3 (B), S27.3 (B), U1.2 (GND), U2.3 (GND)
LCD_BL: CONN1.8, MCU1.15 (P0.11)
LCD_CLK: CONN1.4, MCU1.17 (P0.24)
LCD_CS: CONN1.5, MCU1.25 (P1.01-LF)
LCD_DC: CONN1.6, MCU1.16 (P1.00)
LCD_DIN: CONN1.3, MCU1.18 (P0.22)
LCD_RST: CONN1.7, MCU1.26 (P1.02-LF)
LED_D3V: MCU1.6 (P0.29-LF), U2.2
R0: D4.3 (K), D8.3 (K), D12.3 (K), MCU1.7 (P0.02-LF)
R1: D3.3 (K), D7.3 (K), D11.3 (K), MCU1.8 (P1.15-LF)
R2: D2.3 (K), D6.3 (K), D10.3 (K), MCU1.9 (P1.13-LF)
R3: D1.3 (K), D5.3 (K), D9.3 (K), MCU1.10 (P1.11-LF)
R4: D13.3 (K), D14.3 (K), MCU1.11 (P0.10-LF)
RAW: C1.1, L1.1, MCU1.1 (BAT+), PWR1.3 (C), U1.6 (V_{IN})
ROLLDN: MCU1.27 (P1.07-LF), RE1.C
ROLLUP: MCU1.12 (P0.09-LF), RE1.A

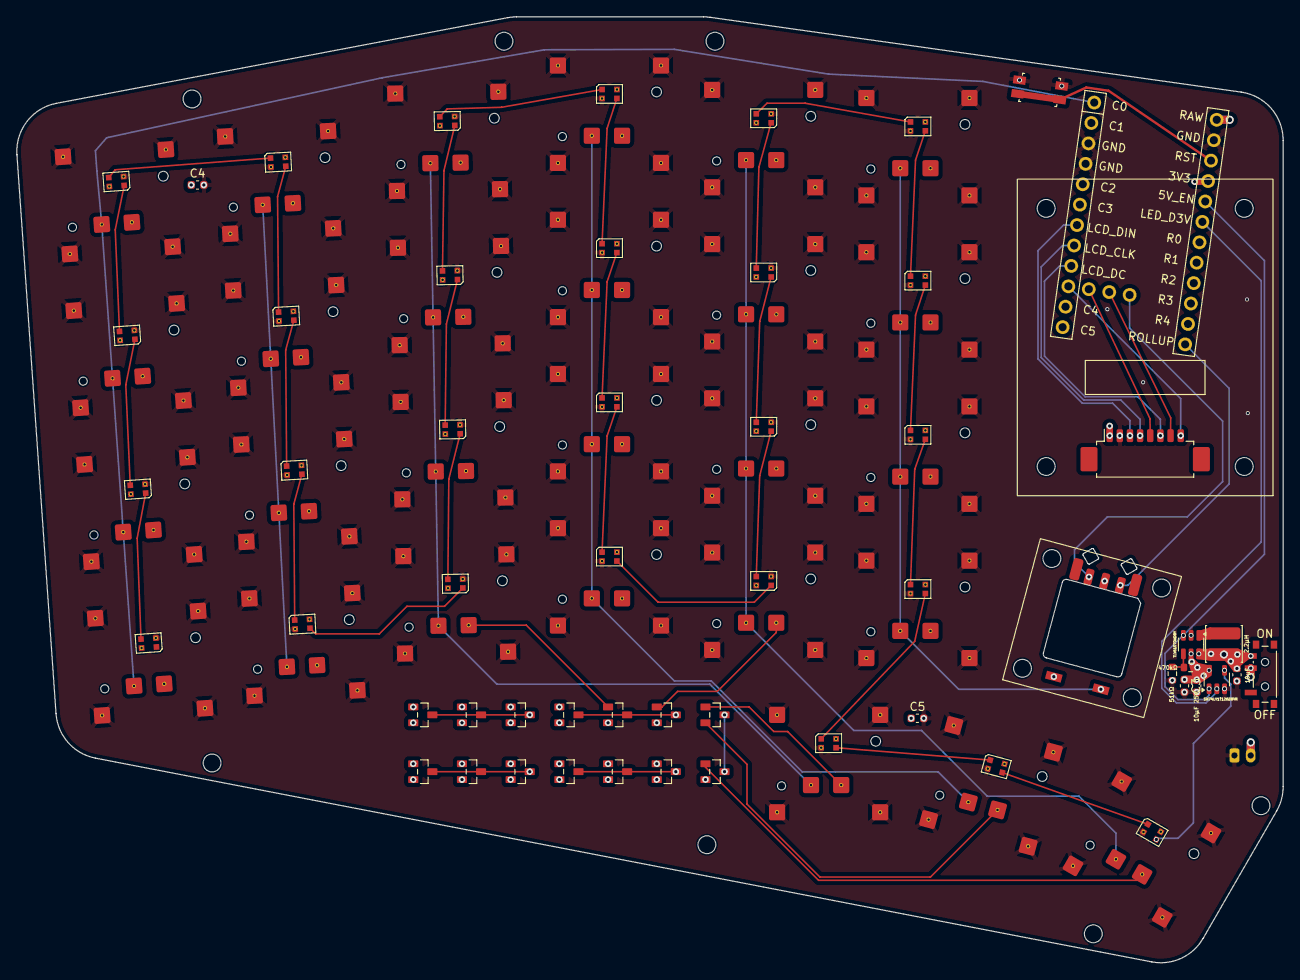
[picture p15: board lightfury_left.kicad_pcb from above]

Board: 6 copper layers, 156.0 x 116.5 mm, 92 parts (1 on the bottom side), 84 nets.

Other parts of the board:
LCD1: LCD_1.69_Waveshare
MH1, MH2, MH3, MH4, MH5, MH6, MH7: mounting_hole_npth

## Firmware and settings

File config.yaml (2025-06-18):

meta:
  engine: 4.1.0
  name: LightFury
  version: 0.1
  ref: &kb_ref "Light Fury v1.0"
  author: huntercook
  url: &kb_url https://github.com/jusdisgi/LightFury
  footprint: &switch_footprint "switch_pg1316s"
  switch:
    $extends: presets.pg1316s
    # Key and keycap measures
    kx: 16
    ky: 16
    ks: 19 # it's a thicc boi
    kp: 19
    keycw: 18 # keycap width (cherry: 18, choc: 17.5)
    keych: 18 # keycap height (cherry: 18, choc: 16.5)

presets:
  # These presets provide different layout options
  # Select a preset in the `units` section below
  # Note: The appropriate switch footprint will still need to be set in the `pcb` section
  mx:
    # Key and keycap measures
    kx: u # spacing between key centers (X-axis)
    ky: u # spacing between key centers (Y-axis)
    ks: 19 # horizontal space between columns (default: 19)
    kp: 19 # vertical padding between keys (deafult: 19)
    kcow: 14 # key cutout hole width (cherry: 14, choc: 13.8)
    kcoh: 14 # key cutout hole height (cherry: 14, choc: 13.8)
    keycw: 18 # keycap width (cherry: 18, choc: 17.5)
    keych: 18 # keycap height (cherry: 18, choc: 16.5)
    led_pos_x: 0 # Led X position relative to the switch center
    led_pos_y: -4.75 # Led Y position relative to the switch center
    led_rotation: 180 # Led rotation
    vertical_underglow_shift: -0.5 kp # How much to shift underglow leds tied to keys
    vertical_diode_shift: 1.325 # How much to shift to avoid overlap
    horizontal_diode_shift: 7.4
    diode_rotation: 0 # Diode rotation
    switch_rotation: 0 # Hotswap north, led south
  choc_v1:
    # Key and keycap measures
    kx: cx # spacing between key centers (X-axis)
    ky: cy # spacing between key centers (Y-axis)
    ks: 18.5 # horizontal space between columns (default: 19)
    kp: 17.5 # vertical padding between keys (deafult: 19)
    kcow: 13.8 # key cutout hole width (cherry, choc v2: 14, choc v1: 13.8)
    kcoh: 13.8 # key cutout hole height (cherry, choc v2: 14, choc v1: 13.8)
    keycw: 17.5 # keycap width (cherry: 18, choc: 17.5)
    keych: 16.5 # keycap height (cherry: 18, choc: 16.5)
    led_pos_x: 0 # Led X position relative to the switch center
    led_pos_y: 4.7 # Led Y position relative to the switch center
    led_rotation: 0 # Led rotation
    vertical_underglow_shift: -kp + 7.8  # How much to shift underglow leds tied to keys
    vertical_diode_shift: 1.5 # How much to shift to avoid overlap
    horizontal_diode_shift: -0.5 kcow - 0.85
    diode_rotation: -180 # Diode rotation
    switch_rotation: 180 # Hotswap south, led north
  choc_v2:
    # Key and keycap measures
    $extends: presets.choc_v1
    kx: u # spacing between key centers (X-axis)
    ky: u # spacing between key centers (Y-axis)
    ks: 19 # horizontal space between columns (default: 19)
    kp: 19 # vertical padding between keys (deafult: 19)
    keycw: 18 # keycap width (cherry: 18, choc: 17.5)
    keych: 18 # keycap height (cherry: 18, choc: 16.5)
  pg1316s:
    # Key and keycap measures
    kx: 16
    ky: 16
    ks: 17 # typical spacing, for example mikefive uses 17x17
    kp: 17
    kcow: 16 # key cutout hole width (Equal to stock keycaps...caps bottom out by design)
    kcoh: 16 # key cutout hole height (Equal to stock keycaps...caps bottom out by design)
    keycw: 16 # keycap width (cherry: 18, choc: 17.5, stock PG1316S: 16)
    keych: 16 # keycap height (cherry: 18, choc: 16.5, stock PG1316S: 16)
    led_pos_x: 0 # Led X coord from key center. 
    led_pos_y: 2.5 # Led Y coord from key center. 2.5 is center of the slot.
    led_rotation: 0 # Led rotation
    vertical_underglow_shift: -0.5 kp  # How much to shift underglow leds tied to keys
    vertical_diode_shift: 1.5 # How much to shift to avoid overlap
    horizontal_diode_shift: -0.5 kcow - 0.85
    diode_rotation: 0 # Diode rotation
    switch_rotation: 0 #LED north
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

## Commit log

2025-06-18 Add all the stuff.
    [board_left.dxf, board_right.dxf, case_inner_wall_left.dxf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]
2026-06-04 Prep for review and paneling
    [JLCPCBA_BOM_Both.xls, JLCPCB_BOM.xls, lightfury_both.kicad_pcb]
2026-06-04 Added capacitors for 5v load smoothing.
    [lightfury_left.kicad_pcb, lightfury_left.kicad_sch, lightfury_right.kicad_pcb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]
2026-06-18 Add LCSC field and populate for BOM.
    [lightfury_left.kicad_pcb, lightfury_left.kicad_sch, lightfury_right.kicad_pcb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]
2026-06-18 Panelize board, generate production files. Production candidate.
    [lightfury_both.kicad_pcb, lightfury_panel.kicad_pcb]
